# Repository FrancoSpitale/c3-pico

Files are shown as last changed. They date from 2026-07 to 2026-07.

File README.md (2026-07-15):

# c3-pico — minimalist ESP32-C3 dev board

A no-frills ESP32-C3 development board in **KiCad 9**: USB-C with native USB,
3.3 V LDO, BOOT/RESET buttons and every usable GPIO on two breadboard-friendly
0.1" rows. Designed to be the board you actually reach for — nothing on it that
a blinky-to-production bring-up doesn't need.

| Top | Bottom |
|---|---|
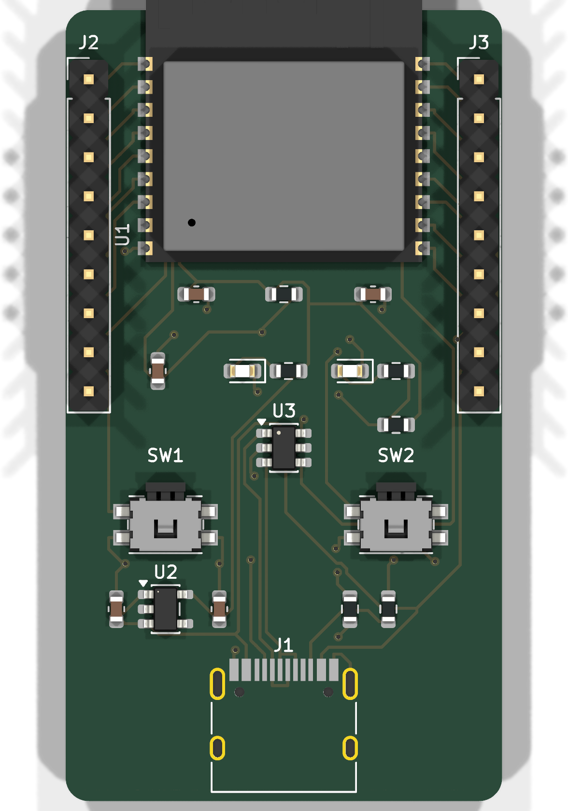
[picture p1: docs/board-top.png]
top
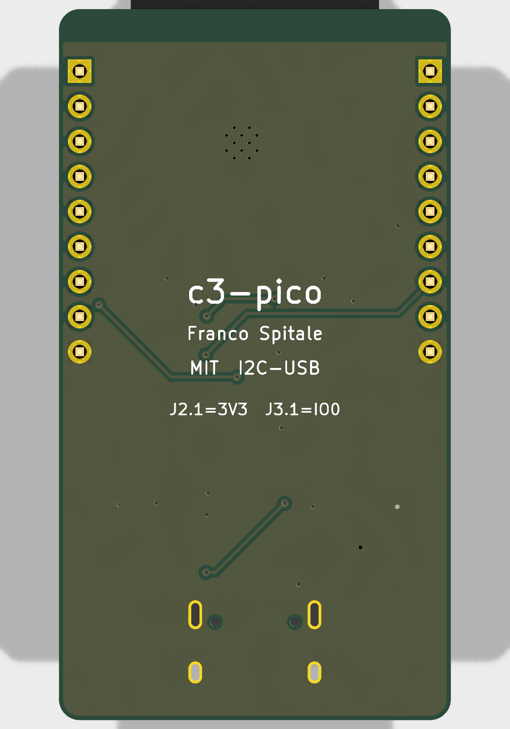
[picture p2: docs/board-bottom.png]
bottom
|  |  |

Schematic: [docs/schematic.svg](docs/schematic.svg) · Source: [hardware/](hardware/)

## Specs

| | |
|---|---|
| MCU | ESP32-C3-WROOM-02-N4 (RIS-V, Wi-Fi + BLE, 4 MB flash) |
| USB | USB-C, native USB-Serial-JTAG (no bridge IC) |
| Power | USB 5 V → AP2112K-3.3 LDO (600 mA) |
| I/O | 13 GPIO on 2 × 1×9 headers, 1.0" apart (breadboard) |
| Board | 28.4 × 51.5 mm, 2-layer, 1.6 mm FR-4 |
| Buttons | BOOT (IO9) + RESET (EN) |
| LEDs | power (green) + user (IO8, blue) |

## Design decisions

**Module, not chip-down.** ESP32-C3-WROOM-02 (PCB antenna, pre-certified RF)
instead of a bare ESP32-C3 with discrete RF. On a hobby/prototyping board the
~US$1 premium buys you regulatory-certified radio and zero antenna-matching
risk on a 2-layer board — chip-down C3 designs want controlled impedance and a
tuned pi network that this class of board can't justify.

**Native USB only, UART on the header.** The C3's built-in USB-Serial-JTAG
(GPIO18/19) goes straight to the USB-C connector — no CP2102/CH340, which
removes a BOM line, a failure mode, and ~US$0.50. GPIO18/19 are therefore *not*
on the headers; UART0 (IO20/IO21) is, for classic serial workflows and as the
escape hatch if an application reconfigures the USB pins.

**USB-C done by the spec.** 5.1 k pulldowns on CC1/CC2 mark the board as a UFP
device, so it powers up from USB-C hosts *and* C-to-C cables/chargers (boards
that skip these only work on A-to-C cables). USBLC6-2SC6 ESD array on D+/D−.

**Strapping pins handled, not hidden.** IO9 (BOOT) has its button; IO8 gets a
10 k pull-up (required high for serial download mode) and doubles as the user
LED, Espressif-devkit style. Both are still broken out — the pull-up is weak
enough to ignore in normal use.

**EN with RC delay.** 10 k pull-up + 1 µF on EN gives a clean power-on ramp and
a proper RESET button without a supervisor chip.

**Antenna overhang + bottom ground plane.** The module hangs off the top edge so
its PCB antenna clears the board copper (with a copper keep-out under the
antenna footprint as a belt-and-suspenders measure). The stackup is the classic
2-layer arrangement — signals and power on top, an unbroken ground plane on the
bottom — so every top trace has a clean return path directly beneath it.

## Pinout

| Left (J2) | Right (J3) |
|---|---|
| 3V3 | IO0 |
| EN | IO1 |
| IO4 | IO2 |
| IO5 | IO3 |
| IO6 | IO21 (TX) |
| IO7 | IO20 (RX) |
| IO8 (LED) | IO10 |
| IO9 (BOOT) | 5V |
| GND | GND |

Header order mirrors the module's physical pin order, so the layout fans out
1:1 with no crossings.

## Fabrication

`fabrication/c3-pico-gerbers-jlcpcb.zip` uploads directly to JLCPCB: 2 layers,
1.6 mm, ENIG recommended (fine-pitch module pads). `c3-pico-bom.csv` and
`c3-pico-pos.csv` are ready for the assembly service — add LCSC part numbers at
order time. The module and USB-C are the only fine-pitch parts; everything else
is 0603 or SOT-23.

## Verification

- ERC: 0 errors, 0 warnings ([hardware/erc.rpt](hardware/erc.rpt))
- DRC: 0 errors, 0 unconnected, 0 clearance/short/edge violations, schematic
  parity OK ([hardware/drc.rpt](hardware/drc.rpt)). One remaining info-level
  notice — U1's library footprint differs from stock because the module's
  antenna silkscreen was trimmed where it overhangs the board edge (deliberate).
- Routing: placed by hand for a clean fan-out, autorouted with
  [freerouting](https://github.com/freerouting/freerouting), then hand-verified.

## Repository layout

```
hardware/     KiCad 9 project (schematic, PCB, ERC/DRC reports)
fabrication/  Gerbers zip (JLCPCB), BOM, pick & place
docs/         Renders and schematic SVG
```

## License

MIT — see [LICENSE](LICENSE). Hardware provided as-is, no warranty; review before
fabricating. Not yet fabricated — if you build one, open an issue with results.

---
*Franco Spitale, 2026. Rev 1.0.*

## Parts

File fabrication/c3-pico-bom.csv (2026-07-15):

Designator | Value | MPN | Footprint | Qty
C1 | 100nF | CL10B104KB8NNNC | Capacitor_SMD:C_0603_1608Metric | 1
C2 | 10uF | CL10A106KP8NNNC | Capacitor_SMD:C_0603_1608Metric | 1
C3-C5 | 1uF | CL10A105KB8NNNC | Capacitor_SMD:C_0603_1608Metric | 3
J1 | USB-C | TYPE-C-31-M-12 | Connector_USB:USB_C_Receptacle_HRO_TYPE-C-31-M-12 | 1
J2,J3 | 1x09_Header |  | Connector_PinHeader_2.54mm:PinHeader_1x09_P2.54mm_Vertical | 2
LED1 | green | KT-0603R-GREEN | LED_SMD:LED_0603_1608Metric | 1
LED2 | blue | KT-0603R-BLUE | LED_SMD:LED_0603_1608Metric | 1
R1,R7 | 10k | RC0603FR-0710KL | Resistor_SMD:R_0603_1608Metric | 2
R3,R4 | 5k1 | RC0603FR-075K1L | Resistor_SMD:R_0603_1608Metric | 2
R5,R6 | 1k | RC0603FR-071KL | Resistor_SMD:R_0603_1608Metric | 2
SW1 | BOOT | EVQ-PUJ02K | Button_Switch_SMD:Panasonic_EVQPUJ_EVQPUA | 1
SW2 | RESET | EVQ-PUJ02K | Button_Switch_SMD:Panasonic_EVQPUJ_EVQPUA | 1
U1 | ESP32-C3-WROOM-02 | ESP32-C3-WROOM-02-N4 | RF_Module:ESP32-C3-WROOM-02 | 1
U2 | AP2112K-3.3 | AP2112K-3.3TRG1 | Package_TO_SOT_SMD:SOT-23-5 | 1
U3 | USBLC6-2SC6 | USBLC6-2SC6 | Package_TO_SOT_SMD:SOT-23-6 | 1

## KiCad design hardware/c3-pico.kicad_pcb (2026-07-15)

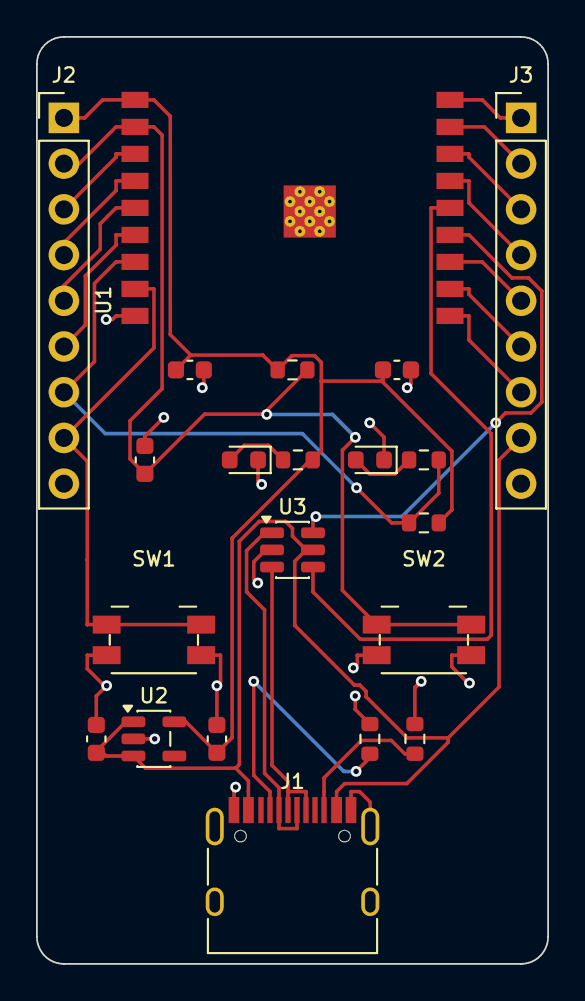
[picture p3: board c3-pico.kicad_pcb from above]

Board: 2 copper layers, 28.4 x 51.5 mm, 21 parts (0 on the bottom side), 25 nets.

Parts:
C1: 100nF; C_0603_1608Metric
C2: 10uF; C_0603_1608Metric
C3, C4, C5: 1uF; C_0603_1608Metric
J1: USB-C; USB_C_Receptacle_HRO_TYPE-C-31-M-12
J2, J3: 1x09_Header; PinHeader_1x09_P2.54mm_Vertical
LED1: green; LED_0603_1608Metric
LED2: blue; LED_0603_1608Metric
R1, R7: 10k; R_0603_1608Metric
R3, R4: 5k1; R_0603_1608Metric
R5, R6: 1k; R_0603_1608Metric
SW1: BOOT; Panasonic_EVQPUJ_EVQPUA
SW2: RESET; Panasonic_EVQPUJ_EVQPUA
U1: ESP32-C3-WROOM-02
U2: AP2112K-3.3; SOT-23-5
U3: USBLC6-2SC6; SOT-23-6

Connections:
+3V3: C1.1, C2.1, C5.1, J2.1, R1.1, R5.2, R7.2, U1.1, U2.5
+5V: C4.1, J1.A4, J1.A9, J1.B4, J1.B9, J3.8, U2.1, U2.3, U3.5
EN: C3.1, J2.2, R1.2, SW2.1, U1.2
GND: C1.2, C2.2, C3.2, C4.2, C5.2, J1.A1, J1.A12, J1.B1, J1.B12, J1.S1, J2.9, J3.9, LED1.1, LED2.1, R3.2, R4.2, SW1.2, SW2.2, U1.9, U1.19, U2.2, U3.2
IO0: J3.1, U1.18
IO1: J3.2, U1.17
IO2: J3.3, U1.16
IO3: J3.4, U1.15
IO4: J2.3, U1.3
IO5: J2.4, U1.4
IO6: J2.5, U1.5
IO7: J2.6, U1.6
IO8: J2.7, R6.2, R7.1, U1.7
IO9: J2.8, SW1.1, U1.8
IO10: J3.7, U1.10
IO20: J3.6, U1.11
IO21: J3.5, U1.12
unnamed: J1.A5, R3.1
unnamed: J1.B5, R4.1
unnamed: J1.A6, J1.B6, U3.3
unnamed: J1.A7, J1.B7, U3.1
unnamed: LED1.2, R5.1
unnamed: LED2.2, R6.1
USB_D+: U1.14, U3.4
USB_D-: U1.13, U3.6

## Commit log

2026-07-15 c3-pico v0.1: schematic for minimalist ESP32-C3 dev board
    ESP32-C3-WROOM-02 + USB-C native USB (no UART bridge), AP2112K LDO,
    CC pulldowns per USB-C spec, USBLC6 ESD, BOOT/RESET, strapping pins
    handled (IO8 pull-up + user LED, IO9 boot button). ERC clean 0/0.
    Layout next.
    [c3-pico.kicad_sch]
2026-07-15 Freeze header pinout to module pin order; document placement
    Reorder J3 to match the module physical right-side pin order so the
    PCB fans out 1:1 without crossings. Update pinout table and status
    (placement done: antenna keep-out, USB-C bottom edge, 1.0in rows).
    Routing (USB-C differential escape) still in progress.
    [c3-pico.kicad_sch]
2026-07-15 Complete PCB layout: routed, DRC-clean, JLCPCB fab files
    2-layer board, 28.4x51.5mm. Hand placement (antenna overhang + keep-out,
    USB-C bottom edge, 1.0in breadboard header rows, 1:1 header fan-out),
    autorouted with freerouting, bottom ground plane. DRC: 0 errors, 0
    unconnected, 0 clearance/short/edge, schematic parity OK (one info notice:
    trimmed the module antenna silk at the board edge). Adds gerbers (JLCPCB
    zip), BOM with MPNs, pick&place, and top/bottom renders.
    [c3-pico-B_Cu.gbl, c3-pico-B_Mask.gbs, c3-pico-B_Paste.gbp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]
